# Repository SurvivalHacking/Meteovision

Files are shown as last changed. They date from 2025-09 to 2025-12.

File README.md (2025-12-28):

# Meteovision
A 3D weather station / Una stazione meteo 3D

## 📘 Descrizione / Description
Meteovision è una stazione meteo fuori dal comune.
Racchiusa in una campana di vetro, trasforma le previsioni del tempo in simboli luminosi: nuvole, fulmini, sole e luna si accendono con eleganza per mostrarti ciò che accadrà nel cielo.
Un anello di luce RGB, controllabile anche tramite APP, accentua l’atmosfera dell’ambiente, mentre un display grafico aggiunge movimento e dettaglio.
Con Meteovision, il meteo non si legge: si guarda, si vive.

Meteovision is an extraordinary weather station.
Enclosed in a glass dome, it transforms weather forecasts into luminous symbols: clouds, lightning, sun, and moon light up elegantly to show you what will happen in the sky.
An RGB light ring, which can also be controlled via an app, accentuates the atmosphere of the environment, while a graphic display adds movement and detail.
With Meteovision, you don't read the weather: you watch it, you experience it.

6b-IMG_0606_(00-00-04-06)

6a-IMG_0602_(00-00-08-22)

6-IMG_0601_(00-00-05-28)

4-IMG_0593_(00-01-49-21)

4-IMG_0593_(00-00-35-11)

4-IMG_0593_(00-00-02-10)

193-screen

---

## 🎛️ Schematic 

Screenshot 2025-09-08 alle 11 39 13

---
## 🎛️ Bill of material / Elenco materiali

* SSD1306 128x32 AMZ: https://amzn.to/3GfbspG
* SSD1306 128x32 ALI: https://s.click.aliexpress.com/e/_oovQgEA
* Anello/Ring 24LED (EXT:85mm/INT:70mm) AMZ: https://amzn.to/44hIzRx
* Vetro per/Glass for Redmi Watch 5 Active AMZ: https://amzn.to/3HZrPqO
* Vetro per/Glass for Redmi Watch 5 Active ALI: https://s.click.aliexpress.com/e/_oD0nSBC
* ESP32C3 AMZ: https://amzn.to/4kt5G2W
* ESP32C3 ALI: https://s.click.aliexpress.com/e/_DDST7Bj
* Pulsante/Pushbutton 6x6x7 DIP: https://s.click.aliexpress.com/e/_opuTCbP
* Resistenza/resistor 220R ALI: https://s.click.aliexpress.com/e/_okkfxGp
* Campana di vetro/Glass dome 9x12cm: https://s.click.aliexpress.com/e/_op1zvwS

Il link proposto è esattamente quella che ho utilizzato, siccome serve solo la parte in vetro è ragionevole pensare che altri tipi proposti da altri venditori siano utilizzabili.
Ho identificato altri 4 venditori che propongono la misura 9x12cm, ma non li ho provati effettivamente e non posso garantire che siano adatti, me se le misure sono rispettate dovrebbe andare benone. In generale se trovate una 'campana di vetro' o 'Glass dome' da 9x12cm dovrebbe andare bene. 
Link alternativi:

The link provided is exactly the one I used. Since only the glass part is needed, it is reasonable to assume that other types offered by other sellers are also suitable. I have identified four other sellers offering the 9x12cm size, but I have not actually tried them and cannot guarantee that they are suitable. However, if the measurements are correct, they should be fine. In general, if you find a 9x12cm ‘glass dome’ or ‘glass bell jar’, it should be fine. Alternative links:
* https://s.click.aliexpress.com/e/_oEAQ9RF
* https://s.click.aliexpress.com/e/_o2bXqxB
* https://s.click.aliexpress.com/e/_oCWLLnF
* Link affiliati / Affiliate links

---
## 👨‍💻 Programmazione modulo
Programmatore WEB (Solo per chrome): https://davidegatti.altervista.org/installaEsp32.php?progetto=MeteoVision

---
# 📝 Revisioni / Revisions
* V1.1 - 09/2025 - L'inserimento della città manualemnte via WEB non funzionava / Manually entering the city via the WEB did not work
* V1.2 - 09/2025 - Aggiunta la possibilità di vedere la previsione del giorno corrente / del giorno dopo e del giorno dopo ancora, mediante menù di configurazione WEB / Added the ability to view the forecast for the current day, the following day, and the day after that via the WEB configuration menu
* V1.3 - 10/2025 - Non erano gestite diverse tipologie di meteo tipo Neve da 600 a 699 e nebbia fumo e altre condizioni particolari da 700 a 799 / Different types of weather conditions such as snow from 600 to 699 and fog, smoke, and other special conditions from 700 to 799 were not managed.
* V1.4 - 10/2025 - Aggiunta scritta in mezzo alle due icone per evidenziare il giorno relativo alle previsioni / Text added between the two icons to highlight the day relating to the forecast. 
* V1.5 - 10/2025 - (By Marco Camerani) Aggiunta Modalità Notturna con orario impostabile da interfaccia web, Indicazione intensità e direzione vento, fix meteo led che non si aggiornano se in modalità diversa auto / Added Night Mode with time settings via web interface, wind speed and direction indicator, LED weather fixes that do not update if in a mode other than auto.
* V1.6 - 10/2025 - Bugfix salvataggio API key rivisto salvataggio di tutte le variabili più robusto gestione città con spazi e nomi lunghi a display
* V1.7 - 11/2025 - aggiunta la possibilita di previsioni 5 giorni e nuova interfaccia web by Marco Prunca
* V1.8 - 12/2025 - Sistemato problema sull'aggiornamento onghi 10 minuti su tutte le modalità
* V1.81 - 12/2025 - Aggiunto swithc per disabilitare l'effetto direzione e velocità del vento sull'anello.
* V1.9 - 12/2025 - Aggiunta animazione anello NeoPixel al cambio modalità e toggle di abilitazione nell'interfaccia web
* V1.91 - 12/2025 - Sistemato bug che facema smettere lèeffetto respiro dell'anello
* V1.92 - 12/2025 - Aggiunta la possibilità di configurare la connessione WIFI in modo manuale. Tutte le istruzioni per la configurazioni sono nel file wifi_config.h by Gigi Soft
* V1.93 - 12/2025 - Sistemato l'effetto respiro quando attivato l'indicatore del vento, e sistemazione per la connessione WIFI by Marco Prunca e Gigi Soft

* Nella cartella stampe 3D bambulab c'è un nuovo set di icone migliorate. / There is a new set of improved icons in the bambulab 3D prints folder.

---
## 🧾 Licenza / License

Questo progetto è distribuito con licenza
**Creative Commons – Attribuzione – Non Commerciale 4.0 Internazionale (CC BY-NC 4.0)**.

Puoi condividerlo e modificarlo liberamente, **citando l’autore**
(Davide Gatti / [survivalhacking](https://github.com/survivalhacking)) e **senza scopi commerciali**.

🔗 [https://creativecommons.org/licenses/by-nc/4.0/](https://creativecommons.org/licenses/by-nc/4.0/)

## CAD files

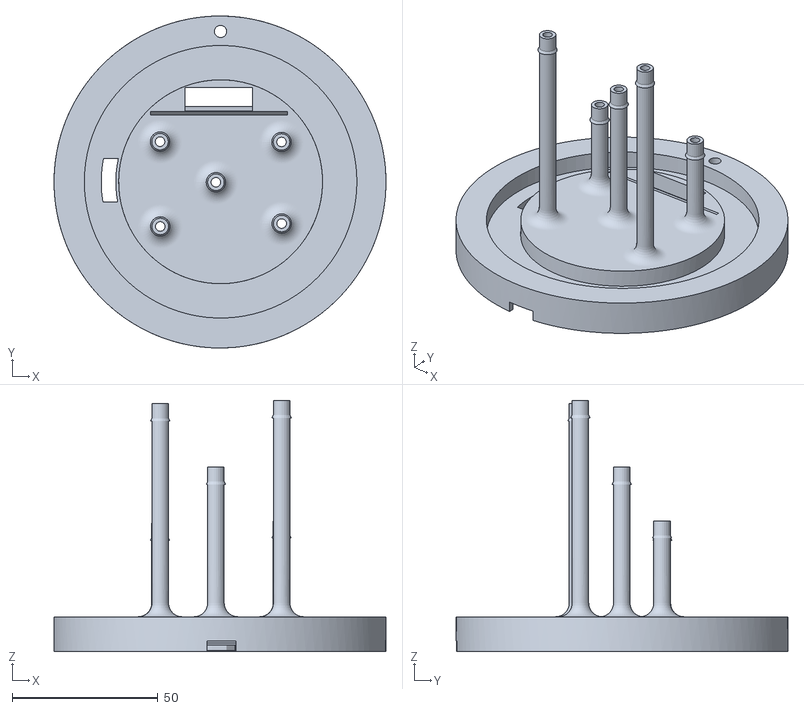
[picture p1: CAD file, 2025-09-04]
3d/Base (Argento glitter).stl
114.0 x 114.0 x 86.3

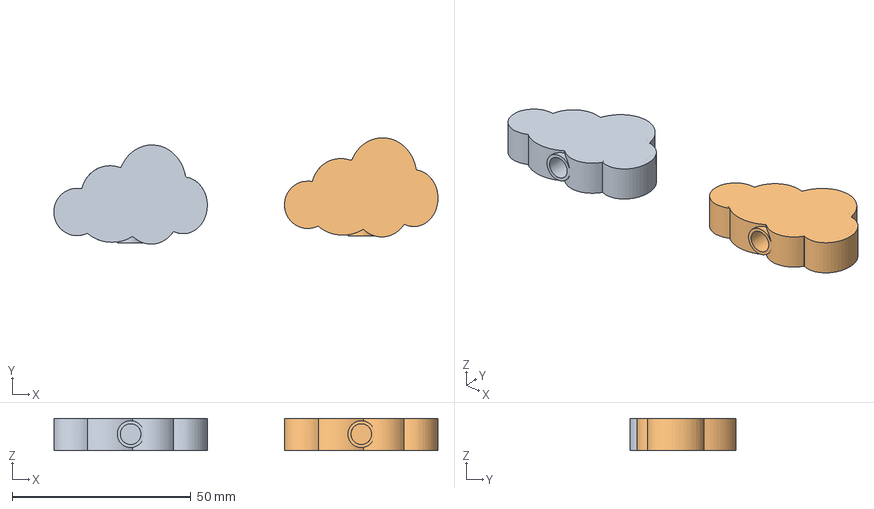
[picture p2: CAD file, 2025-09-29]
3d/Elementi COLOR/ANYCUBIC/Nuvola (AZZURRO-BIANCO) Anycubic.3mf
107.4 x 29.7 x 9.02 mm
Stunning Jaagub-Lappi (10).stl x 2

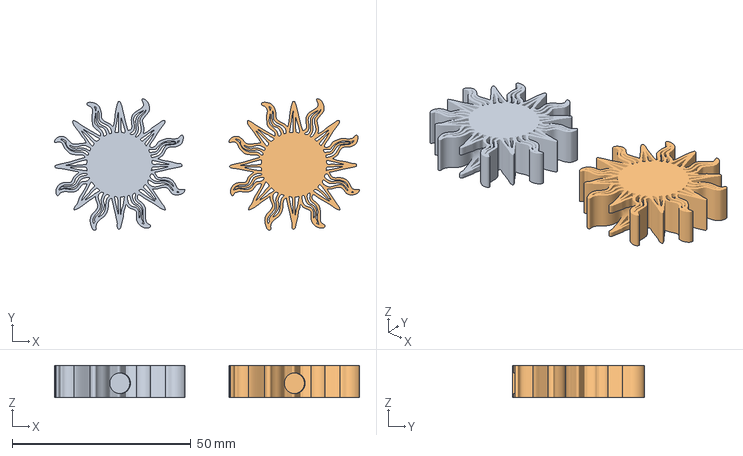
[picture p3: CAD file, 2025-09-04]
3d/Elementi COLOR/BAMBU/Sole (GIALLO-BIANCO Bambu.3mf
85.2 x 36.7 x 9.00 mm
SOLE.stl x 2

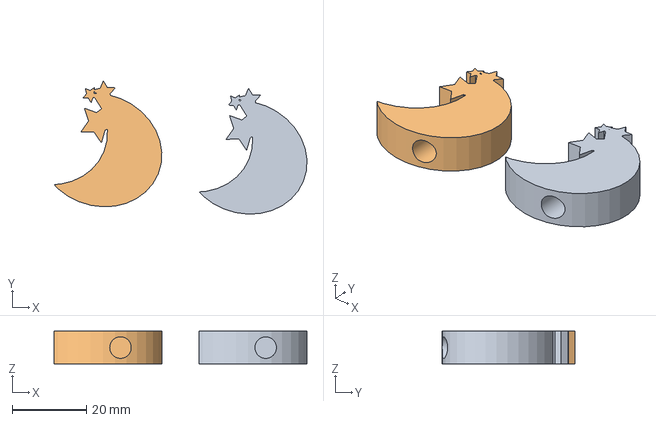
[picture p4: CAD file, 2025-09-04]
3d/Elementi COLOR/CREALITY/Luna (GRIGIO-BIANCO) Creality.3mf
68.2 x 35.9 x 8.86 mm
luna x 2

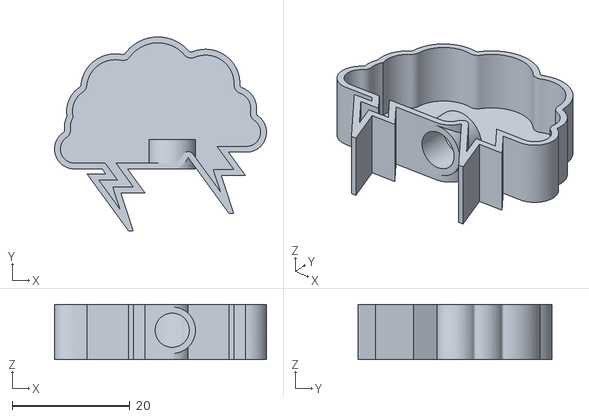
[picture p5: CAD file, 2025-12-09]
3d/Meteovision NEW ICON 5.8/FULMINI/Meteovision Foro 5.stl
36.0 x 32.9 x 9.40

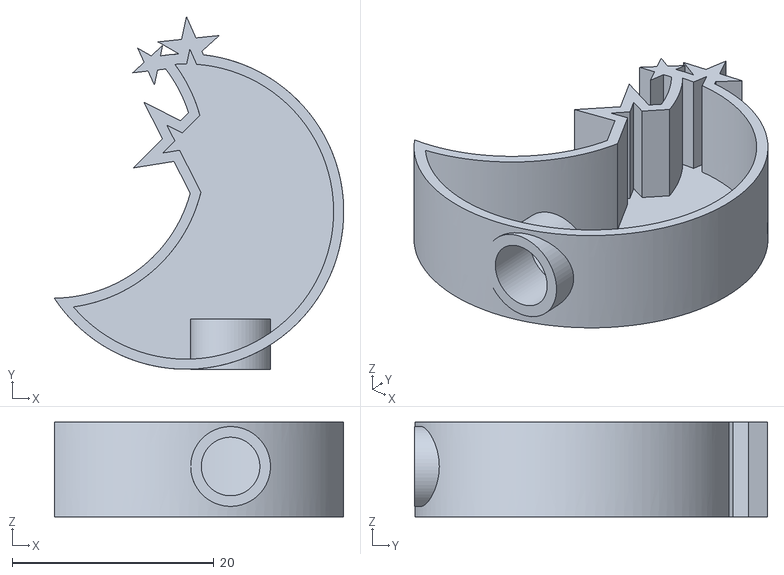
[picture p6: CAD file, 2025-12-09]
3d/Meteovision NEW ICON 5.8/LUNA/Luna_Base_Bianco.stl
28.7 x 35.0 x 9.40

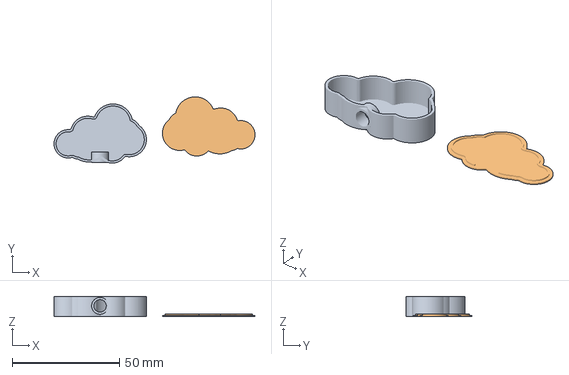
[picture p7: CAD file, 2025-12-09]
3d/Meteovision NEW ICON 5.8/NUVOLA/Nuvola_Cover_Bianco.3mf
93.8 x 30.9 x 9.40 mm
Nuvola2_Base_Azzurro.stl
Nuvola2_Cover_Azzurro.stl

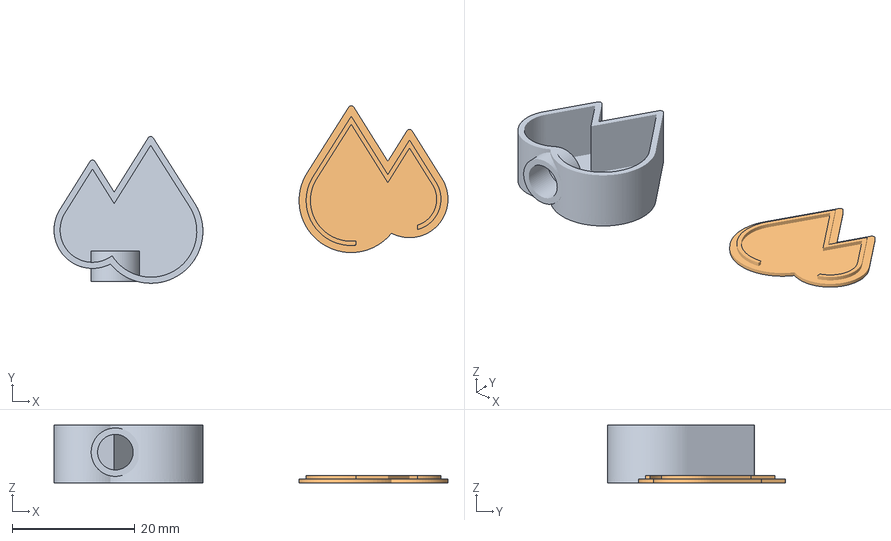
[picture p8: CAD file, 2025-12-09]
3d/Meteovision NEW ICON 5.8/PIOGGIA/Pioggia_Cover_Bianco.3mf
64.3 x 29.0 x 9.40 mm
Gocce_Base_Bianco.stl
Gocce_Cover_Bianco.stl

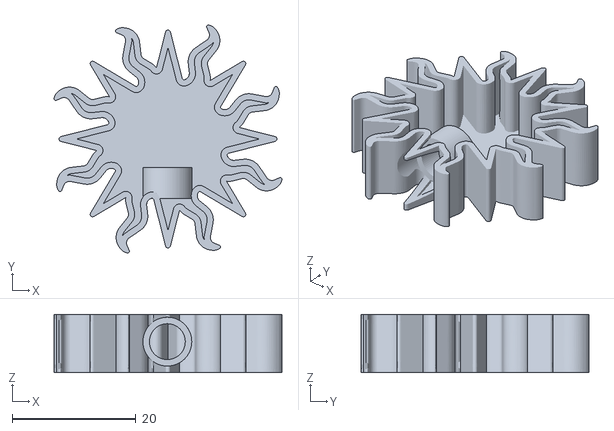
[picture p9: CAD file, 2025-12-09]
3d/Meteovision NEW ICON 5.8/SOLE/Sole_Base_Bianco.stl
36.9 x 36.9 x 9.40

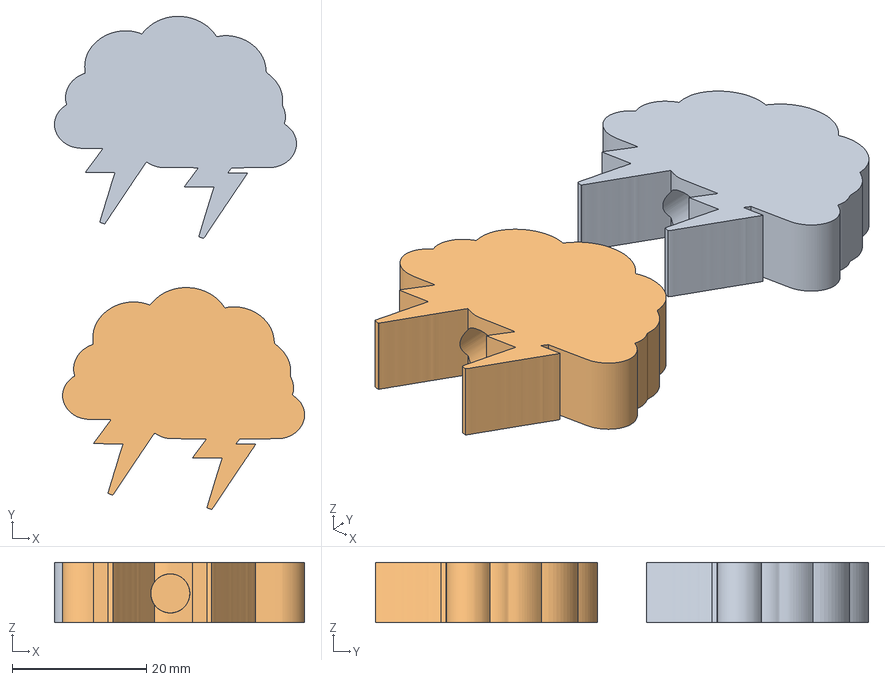
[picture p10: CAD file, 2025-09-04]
3d/Elementi COLOR/CREALITY/Fulmini (VIOLA-BIANCO) Creality.3mf
37.2 x 73.3 x 8.99 mm
Assemblaggio x 2

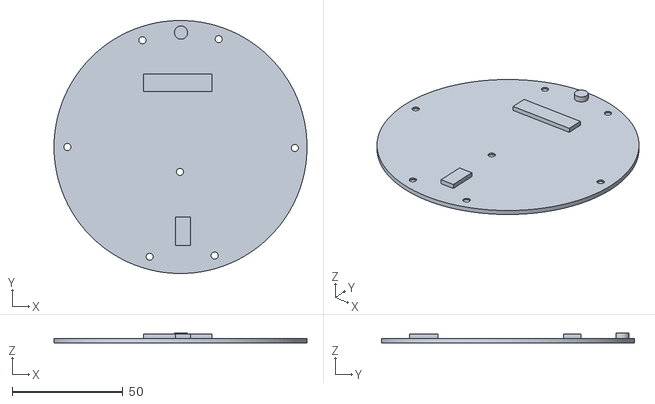
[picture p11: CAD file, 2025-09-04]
3d/Fondo (Argento glitter).stl
114.0 x 114.0 x 4.50

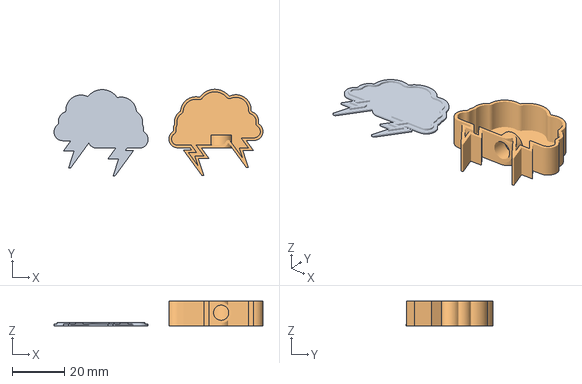
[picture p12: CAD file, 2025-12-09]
3d/Meteovision NEW ICON 5.8/FULMINI/Fulmine_Cover_Bianco.3mf
79.9 x 33.1 x 9.40 mm
Fulmine_Cover_Bianco.stl
Meteovision Foro 5.stl

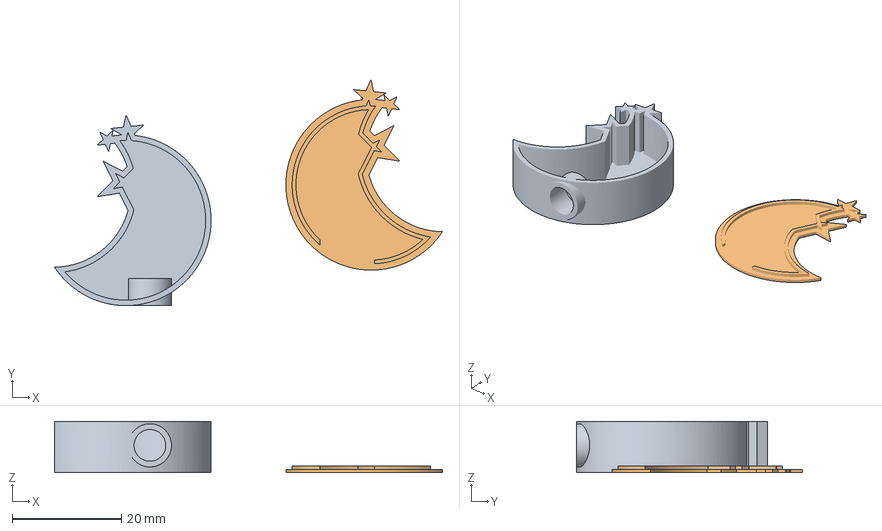
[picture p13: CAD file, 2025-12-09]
3d/Meteovision NEW ICON 5.8/LUNA/Luna_Cover_Bianco.3mf
71.0 x 41.5 x 9.40 mm
Luna_Base_Bianco.stl
Luna_Cover_Bianco.stl

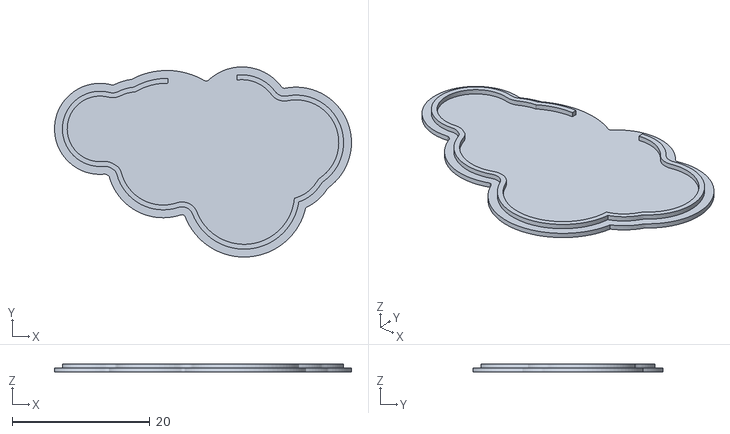
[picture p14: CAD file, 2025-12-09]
3d/Meteovision NEW ICON 5.8/NUVOLA/Nuvola2_Cover_Azzurro.stl
43.1 x 27.6 x 1.20

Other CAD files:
3d/Elementi COLOR/ANYCUBIC/Luna (GRIGIO-BIANCO) Anycubic.3mf
3d/Elementi COLOR/BAMBU/Nuvola (AZZURRO-BIANCO) Bambu.3mf
3d/Meteovision NEW ICON 5.8/PIOGGIA/Gocce_Cover_Bianco.stl
3d/Meteovision NEW ICON 5.8/SOLE/Sole_Cover_Bianco.3mf
3d/Anello (Traparente).stl
3d/Elementi (BIANCHI).stl
3d/Elementi COLOR/ANYCUBIC/Fulmini (VIOLA-BIANCO) Anycubic.3mf
3d/Elementi COLOR/ANYCUBIC/Gocce (BLU-BIANCO) Aycubic.3mf
3d/Elementi COLOR/ANYCUBIC/Sole (GIALLO-BIANCO Anycubic.3mf
3d/Elementi COLOR/BAMBU/Fulmini (VIOLA-BIANCO) Bambu.3mf
3d/Elementi COLOR/BAMBU/Gocce (BLU-BIANCO) Bambu.3mf
3d/Elementi COLOR/BAMBU/Luna (GRIGIO-BIANCO) Bambu.3mf
3d/Elementi COLOR/CREALITY/Gocce (BLU-BIANCO) Crality.3mf
3d/Elementi COLOR/CREALITY/Nuvola (AZZURRO-BIANCO) Creality.3mf
3d/Elementi COLOR/CREALITY/Sole (GIALLO-BIANCO Creality.3mf
3d/Meteovision NEW ICON 5.8/FULMINI/Fulmine_Cover_Bianco.stl
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

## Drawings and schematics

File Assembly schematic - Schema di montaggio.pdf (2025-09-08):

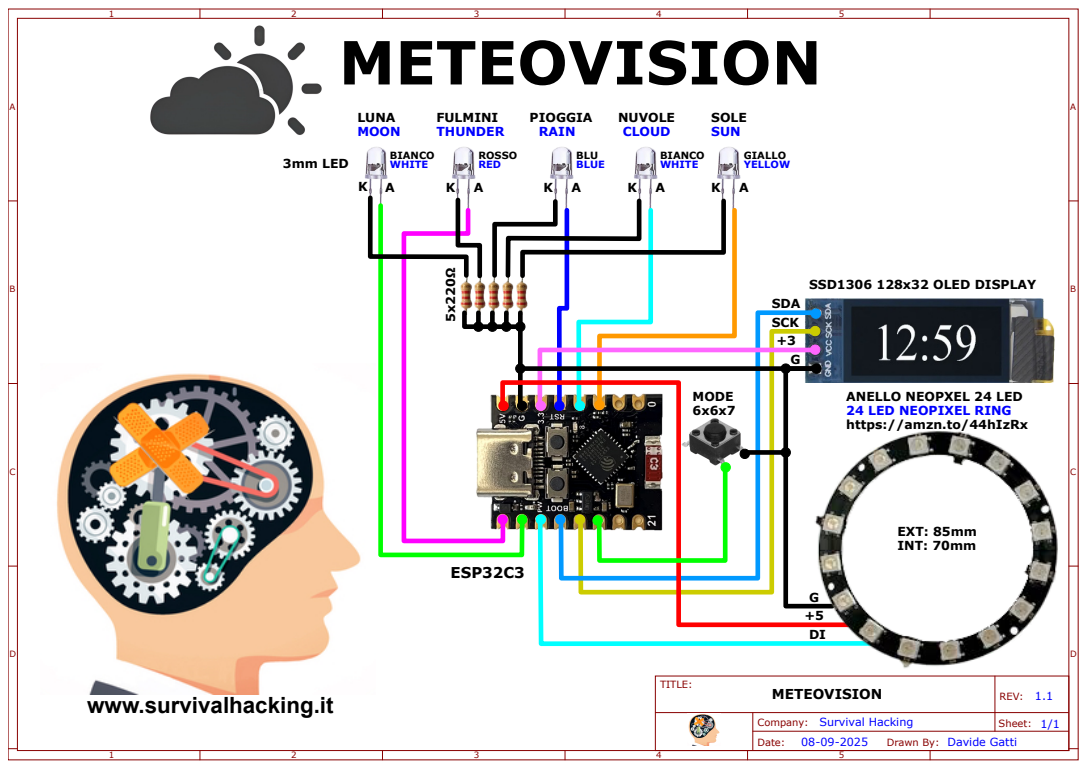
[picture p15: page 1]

SCK
+3

MODE
6x6x7

TITLE: | REV: 1.1

Company: Survival Hacking | Sheet: 1/1

Drawn By: Davide Gatti

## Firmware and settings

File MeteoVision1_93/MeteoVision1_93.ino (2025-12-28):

// V1.0 - 06/2025 - Meteovision by Davide Gatti - 2025 - www.survivalhacking.it
// V1.1 - 09/2025 - L'inserimento della città manualemnte via WEB non funzionava
// V1.2 - 09/2025 - Aggiunta la possibilità di vedere la previsione del giorno corrente / del giorno dopo e del giorno dopo ancora, mediante menù di configurazione WEB
// V1.3 - 10/2025 - Non erano gestite diverse tipologie di meteo tipo Neve da 600 a 699 e nebbia fumo e altre condizioni particolari da 700 a 799
// V1.4 - 10/2025 - Aggiunta scritta in mezzo alle due icone per evidenziare il giorno relativo alle previsioni
// V1.5 - 10/2025 - Aggiunta Modalità Notturna con orario impostabile da interfaccia web, Indicazione intensità e direzione vento, fix meteo led che non si aggiornano se in modalità diversa auto
// V1.6 - 10/2025 - Bugfix salvataggio API key rivisto salvataggio di tutte le variabili più robusto gestione città con spazi e nomi lunghi a display
// V1.7 - 11/2025 - aggiunta la possibilita di previsioni 5 giorni e interfaccia web by Marco Prunca
// V1.8 - 11/2025 - FIX: Aggiornamento meteo ogni 10 minuti funzionante per tutte le modalità
// V1.81- 12/2025 - Aggiunto swithc per disabilitare l'effetto direzione e velocità del vento sull'anello.
// V1.9 - 12/2025 - Aggiunta animazione anello NeoPixel al cambio modalità e toggle di abilitazione nell'interfaccia web
// V1.91- 12/2025 - Sistemato bug che facema smettere lèeffetto respiro dell'anello
// V1.92- 12/2025 - Aggiunta la possibilità di configurare la connessione WIFI in modo manuale. Tutte le istruzioni per la configurazioni sono nel file wifi_config.h by Gigi Soft
// V1.93- 12/2025 - Sistemato l'effetto respiro quando attivato l'indicatore del vento, e sistemazione per la connessione WIFI by Marco Prunca e Gigi Soft

#include <Arduino.h>
#include <Wire.h>
#include <Adafruit_GFX.h>       // Libreria grafica per display OLED
#include "Adafruit_SSD1306.h"   // Libreria per SSD1306 modificata per il supporto mirroring
#include <Adafruit_NeoPixel.h>  // Controllo anello LED WS2812

// Gestione connessione WiFi automatica
#include <WiFiManager.h>  // Permette setup Wi-Fi via interfaccia web

// Richieste HTTP per ottenere i dati meteo
#include <HTTPClient.h>
#include <ArduinoJson.h>  // Parsing JSON della risposta OpenWeather

#include "graphics.h"  // Contiene animazioni bitmap per display

// -- LIBRERIE PER GESTIONE TEMPO --
// Tempo standard C
#include <ctime>       // Include strutture come time_t, struct tm
#include <time.h>      // Funzioni di conversione ora/data
#include <sys/time.h>  // Per strutture temporali compatibili con ESP32

// Librerie NTP (Network Time Protocol)
#include <NTPClient.h>  // Permette sincronizzazione ora via Internet
#include <WiFiUdp.h>    // Necessario per comunicazione UDP usata da NTPClient

// Librerie custom per server web
#include <WebServer.h>    // Server HTTP in esecuzione su ESP32
#include <Preferences.h>  // Per salvare configurazioni persistenti

#include "secret.h"       // File con chiavi/API sensibili
#include "wifi_config.h"  // Configurazione WiFi manuale

// -- DEFINIZIONI HARDWARE DISPLAY OLED --
#define OLED_WIDTH 128
#define OLED_HEIGHT 32  // MODIFICATO: da 64 a 32 pixel
#define OLED_ADDR 0x3C  // Indirizzo I2C predefinito per display SSD1306
#define OLED_RESET -1   // Se il pin RESET non è collegato

// Istanzia il display OLED
Adafruit_SSD1306 display(OLED_WIDTH, OLED_HEIGHT, &Wire, OLED_RESET);

// -- DEFINIZIONI LED METEO INDIVIDUALI --
#define PIN_LED_SOLE 2       // LED per stato soleggiato
#define PIN_LED_NUVOLE 3     // LED per nuvole
#define PIN_LED_PIOGGIA 4    // LED per pioggia
#define PIN_LED_TEMPORALE 5  // LED per temporale
#define PIN_LED_LUNA 6       // LED per condizione notturna

// -- DEFINIZIONI PER ANELLO NEOPIXEL --
#define PIN_NEOPIXEL 7
#define NUM_NEOPIXELS 24  // Numero LED sull'anello
Adafruit_NeoPixel pixels(NUM_NEOPIXELS, PIN_NEOPIXEL, NEO_GRB + NEO_KHZ800);

// -- DEFINIZIONE PULSANTE FISICO --
#define PIN_PULSANTE 10  // Pulsante per cambiare modalità/luminosità

// -- DEFINIZIONI PER TEMPISMO DI SCHERMATA E METEO --
#define SCREEN_TEXT_DURATION 8000              // MODIFICATO: Ridotto per display più piccolo
#define SCREEN_ANIMATION_DURATION 5000         // MODIFICATO: Ridotto per display più piccolo
#define WEATHER_FETCH_INTERVAL 10 * 60 * 1000  // Ogni 10 minuti (in ms)

// Parametri effetto "respiro" LED (NeoPixel)
#define NEOPIXEL_BREATH_MIN 25       // Luminosità minima effetto respiro
#define NEOPIXEL_BREATH_MAX 255      // Luminosità massima
#define BREATH_UPDATE_SPEED 5        // Velocità animazione
#define NEOPIXEL_BOOT_ANIM_DELAY 50  // Delay tra accensioni LED iniziali

// Variabili per la gestione del pulsante
unsigned long buttonPressStartTime = 0;
bool buttonState = HIGH;
bool lastButtonState = HIGH;
unsigned long lastDebounceTime = 0;
const unsigned long debounceDelay = 50;
bool keypressed = false;

// Variabili per pressione lunga del pulsante
bool isLongPressMode = false;
const unsigned long LONG_PRESS_THRESHOLD = 1000;
const int BRIGHTNESS_CHANGE_INTERVAL = 100;
unsigned long lastBrightnessChangeTime = 0;

unsigned long lastScreenChange = 0;
bool showText = true;

// -- VARIABILI DI CONFIGURAZIONE PERSISTENTE --
Preferences preferences;

// Valori persistenti da conservare
char savedCity[40] = "Monza";
char savedCountryCode[5] = "IT";
int savedNeopixelBrightness = 200;
int savedMode = 0;
bool DisplayOneTime = false;
int Currentmode = 0;
int forecastDay = -1; // -1: Attuale (sempre all'accensione)
int forecastPeriod = 0; // 0: Mattino, 1: Pomeriggio, 2: Sera
#define MAX_MODE 11
bool nightModeEnabled = false;
int nightStartHour = 22;
int nightStartMinute = 00;
int nightEndHour = 7;
int nightEndMinute = 00;
bool windAnimationEnabled = true;
bool neopixelAnimationEnabled = true; // Nuova variabile per animazione cambio modalità

// Variabili per la visualizzazione del nome della modalità
bool showModeName = false;
unsigned long modeNameStartTime = 0;
const unsigned long MODE_NAME_DISPLAY_DURATION = 2000; // MODIFICATO: da 1 a 2 secondi

// Definizione delle modalità disponibili
#define MODO_AUTO 0
#define MODO_ROSSO 1
#define MODO_VERDE 2
#define MODO_BLU 3
#define MODO_VIOLA 4
#define MODO_CIANO 5
#define MODO_GIALLO 6
#define MODO_BIANCO 7
#define MODO_RING_OFF 8
#define MODO_LED_OFF 9
#define MODO_ALL_OFF 10
#define MODO_NOTTE 11

// -- VARIABILI GLOBALI NON SALVATE IN MEMORIA --
String ProductName = "MeteoVision V1.93";
String weatherDescription = "Ricerca...";
float windSpeed = 0;
int windDirection = 0;
int weatherConditionCode = 0;
float temperatureCelsius = 0.0;
int humidity = 0;
time_t sunriseTime = 0;
time_t sunsetTime = 0;
int animationFrame = 0;
const unsigned long WIND_SCAN_DURATION = 1000;
bool windScanning = false;
bool windAnimationActive = false;
int windScanFrame = 0;
unsigned long windAnimationStartTime = 0;
unsigned long animationStartTime = 0;
int windLedIndex = 0;

// Flag per forzare l'aggiornamento immediato del meteo
bool forceWeatherUpdate = false;

// Timer per l'aggiornamento periodico del meteo
unsigned long lastWeatherFetch = 0;

// -- GESTIONE RETE E SERVER WEB --
WiFiManager wm;
WebServer server(80);

// -- CLIENT NTP PER L'ORARIO DI SISTEMA --
WiFiUDP ntpUDP;
NTPClient timeClient(ntpUDP, "pool.ntp.org", 0, 60000);

// -- VARIABILI PER ANIMAZIONE DELL'ANELLO NEOPIXEL --
bool neopixelAnimationActive = true;
uint32_t neopixelBaseColor = pixels.Color(0, 0, 0);
bool neopixelBootAnimationInProgress = false;
bool neopixelModeChangeAnimation = false; // Nuova variabile per animazione cambio modalità
int neopixelAnimStep = 0;
unsigned long neopixelAnimLastUpdate = 0;
const int NEOPIXEL_ANIM_STEPS = NUM_NEOPIXELS + 5; // Numero di passi dell'animazione (LED + 5 extra per completamento)
const unsigned long NEOPIXEL_ANIM_DELAY = 40; // Delay tra i passi (più veloce per effetto fluido)

// Parametro personalizzato globale per WiFiManager
WiFiManagerParameter custom_api_key("api_key", "OpenWeatherMap API Key", "", 60);

// --- Connessione WiFi Manuale ---
bool connectWiFiManual() {
  Serial.println("\n==================================");
  Serial.println("TENTATIVO CONNESSIONE WIFI MANUALE");
  Serial.println("==================================");
  Serial.print("SSID: ");
  Serial.println(WIFI_SSID);
  Serial.print("Timeout: ");
  Serial.print(WIFI_CONNECT_TIMEOUT / 1000);
  Serial.println(" secondi");
  
  display.clearDisplay();
  display.setTextSize(1);
  display.setTextColor(SSD1306_WHITE);
  display.setCursor(0, 0);
  display.println("WiFi Manuale...");
  display.setCursor(0, 10);
  display.println("SSID:");
  display.setCursor(0, 18);
  display.println(WIFI_SSID);
  display.display();
  
  WiFi.disconnect(true);  
  delay(100);
  WiFi.mode(WIFI_STA);
  WiFi.begin(WIFI_SSID, WIFI_PASSWORD);
  
  unsigned long startAttempt = millis();
  int dotCount = 0;
  
  while (WiFi.status() != WL_CONNECTED && (millis() - startAttempt) < WIFI_CONNECT_TIMEOUT) {
    delay(500);
    Serial.print(".");
    
    dotCount = (dotCount + 1) % 4;
    display.clearDisplay();
    display.setTextSize(1);
    display.setCursor(0, 0);
    display.println("Connessione");
    display.setCursor(0, 10);
    for(int i = 0; i < dotCount; i++) {
      display.print(".");
    }
    display.setCursor(0, 20);
    display.print("Tempo: ");
    display.print((millis() - startAttempt) / 1000);
    display.print("s");
    display.display();
  }
  
  Serial.println();
  
  if (WiFi.status() == WL_CONNECTED) {
    Serial.println("✓ CONNESSIONE RIUSCITA!");
    Serial.print("Indirizzo IP: ");
    Serial.println(WiFi.localIP());
    Serial.print("Signal Strength (RSSI): ");
    Serial.print(WiFi.RSSI());
    Serial.println(" dBm");
    
    display.clearDisplay();
    display.setTextSize(1);
    display.setCursor(0, 0);
    display.println("WiFi CONNESSO!");
    display.setCursor(0, 10);
    display.print("IP: ");
    display.println(WiFi.localIP());
    display.setCursor(0, 20);
    display.print("RSSI: ");
    display.print(WiFi.RSSI());
    display.println("dBm");
    display.display();
    delay(3000);
    
    return true;
  } else {
    Serial.println("✗ CONNESSIONE FALLITA!");
    Serial.print("Stato WiFi: ");
    
    switch(WiFi.status()) {
      case WL_NO_SSID_AVAIL:
        Serial.println("SSID non trovato");
        display.clearDisplay();
        display.setTextSize(1);
        display.setCursor(0, 8);
        display.println("ERRORE WiFi:");
        display.setCursor(0, 16);
        display.println("SSID non trovato");
        break;
      case WL_CONNECT_FAILED:
        Serial.println("Password errata");
        display.clearDisplay();
        display.setTextSize(1);
        display.setCursor(0, 8);
        display.println("ERRORE WiFi:");
        display.setCursor(0, 16);
        display.println("Password errata");
        break;
      default:
        Serial.println("Errore sconosciuto");
        display.clearDisplay();
        display.setTextSize(1);
        display.setCursor(0, 8);
        display.println("ERRORE WiFi:");
        display.setCursor(0, 16);
        display.println("Timeout");
        break;
    }
    display.display();
    delay(3000);
    
    return false;
  }
}


// --- Mappatura traduzioni OpenWeatherMap (da codice numerico a descrizione ITA) ---
String getWeatherDescriptionItalian(int conditionCode) {
  if (conditionCode >= 200 && conditionCode < 300) return "Temporale";
  if (conditionCode >= 300 && conditionCode < 400) return "Pioggerella";
  if (conditionCode >= 500 && conditionCode < 600) {
    if (conditionCode == 500) return "Pioggia leggera";
    if (conditionCode == 501) return "Pioggia moderata";
    if (conditionCode == 502) return "Pioggia intensa";
    if (conditionCode == 503) return "Pioggia molto intensa";
    if (conditionCode == 504) return "Pioggia estrema";
    if (conditionCode == 511) return "Pioggia gelata";
    if (conditionCode == 520) return "Pioggerella intensa";
    if (conditionCode == 521) return "Acquazzone";
    if (conditionCode == 522) return "Forti acquazzoni";
    if (conditionCode == 531) return "Acquazzone irregolare";
    return "Pioggia";
  }
  if (conditionCode >= 600 && conditionCode < 700) return "Neve";
  if (conditionCode >= 700 && conditionCode < 800) {
    if (conditionCode == 701) return "Nebbia";
    if (conditionCode == 711) return "Fumo";
    if (conditionCode == 721) return "Foschia";
    if (conditionCode == 731) return "Vortici di sabbia/polvere";
    if (conditionCode == 741) return "Nebbia";
    if (conditionCode == 751) return "Sabbia";
    if (conditionCode == 761) return "Polvere";
    if (conditionCode == 762) return "Cenere vulcanica";
    if (conditionCode == 771) return "Colpo di vento";
    if (conditionCode == 781) return "Tornado";
    return "Atmosferico";
  }
  if (conditionCode == 800) return "Cielo sereno";
  if (conditionCode == 801) return "Poche nuvole";
  if (conditionCode == 802) return "Nuvole sparse";
  if (conditionCode == 803) return "Nuvole irregolari";
  if (conditionCode == 804) return "Cielo coperto";

  return "Sconosciuto";
}
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
void loop() {
  #if !USE_MANUAL_WIFI
    wm.process();
  #endif

  server.handleClient();
  handleButtonPress();

  unsigned long currentTime = millis();

  // --- GESTIONE CENTRALIZZATA DELL'AGGIORNAMENTO METEO ---
  // SPOSTATO QUI IN CIMA: viene eseguito SEMPRE, anche durante regolazione luminosità o cambio modalità
  // Controlla se è necessario un aggiornamento del meteo
  if (forceWeatherUpdate || (currentTime - lastWeatherFetch >= WEATHER_FETCH_INTERVAL)) {
    if (forceWeatherUpdate) {
      Serial.println("Aggiornamento forzato del meteo richiesto");
    } else {
      Serial.println("Aggiornamento periodico del meteo (10 minuti)");
    }

    fetchWeather();
    lastWeatherFetch = currentTime;
    forceWeatherUpdate = false;

    // Dopo l'aggiornamento, mostra le informazioni testuali
    lastScreenChange = currentTime;
    showText = true;
    DisplayOneTime = false;

    // Se siamo in modalità AUTO, aggiorna anche i LED
    if (Currentmode == MODO_AUTO) {
      updateWeatherLEDs();
      // Esegui l'animazione a onda fluida con il colore del meteo
      neopixelModeChangeAnimation = true;
      neopixelAnimStep = 0;
      neopixelAnimLastUpdate = millis();
    }
  }

  // Se siamo in modalità regolazione luminosità, non eseguire il resto del loop normale
  if (isLongPressMode) {
    return;
  }

  checkNightMode();

  // Gestione dell'animazione cambio modalità NeoPixel
  runNeopixelModeChangeAnimation();

  // Gestione della visualizzazione del nome della modalità
  if (showModeName) {
    if (millis() - modeNameStartTime >= MODE_NAME_DISPLAY_DURATION) {
      showModeName = false;
      // Torna alla visualizzazione normale del meteo
      showText = true;
      DisplayOneTime = false;
    } else {
      // Se stiamo mostrando il nome della modalità, non fare altro
      // Il display non viene aggiornato, quindi rimane il nome della modalità
      return;
    }
  }

  if (keypressed == false) {
    // GESTIONE MODALITÀ CON COMPORTAMENTI DIVERSI
    if (Currentmode == MODO_NOTTE) {
      // Modalità notte: solo display attivo, tutti i LED spenti
      if (showText) {
        if (currentTime - lastScreenChange >= SCREEN_TEXT_DURATION) {
          showText = false;
          lastScreenChange = currentTime;
          display.clearDisplay();
          currentFrame = 0;
        }
        if (!DisplayOneTime) {
          displayWeatherInfo();
          DisplayOneTime = true;
        }
      } else {
        if (currentTime - lastScreenChange >= SCREEN_ANIMATION_DURATION) {
          showText = true;
          lastScreenChange = currentTime;
          display.clearDisplay();
        }
        displayWeatherAnimation();
        DisplayOneTime = false;
      }
    }
    else if (Currentmode == MODO_ALL_OFF) {
      // Modalità tutto spento: display spento, tutti i LED spenti
      display.clearDisplay();
      display.display();
      AllLEDoff();
      pixels.clear();
      pixels.show();
    }
    else if (Currentmode == MODO_LED_OFF) {
      // Modalità LED spenti: solo display attivo, LED individuali spenti, anello spento
      if (showText) {
        if (currentTime - lastScreenChange >= SCREEN_TEXT_DURATION) {
          showText = false;
          lastScreenChange = currentTime;
          display.clearDisplay();
          currentFrame = 0;
        }
        if (!DisplayOneTime) {
          displayWeatherInfo();
          DisplayOneTime = true;
        }
      } else {
        if (currentTime - lastScreenChange >= SCREEN_ANIMATION_DURATION) {
          showText = true;
          lastScreenChange = currentTime;
          display.clearDisplay();
        }
        displayWeatherAnimation();
        DisplayOneTime = false;
      }
      
      // Assicura che i LED siano spenti
      AllLEDoff();
      pixels.clear();
      pixels.show();
    }
    else if (Currentmode == MODO_RING_OFF) {
      // Modalità anello spento: display attivo, LED individuali attivi, anello spento
      if (showText) {
        if (currentTime - lastScreenChange >= SCREEN_TEXT_DURATION) {
          showText = false;
          lastScreenChange = currentTime;
          display.clearDisplay();
          currentFrame = 0;
        }
      } else {
        if (currentTime - lastScreenChange >= SCREEN_ANIMATION_DURATION) {
          showText = true;
          lastScreenChange = currentTime;
          display.clearDisplay();
        }
      }

      if (showText) {
        if (!DisplayOneTime) {
          displayWeatherInfo();
          DisplayOneTime = true;
        }
      } else {
        displayWeatherAnimation();
        DisplayOneTime = false;
      }
      
      // Anello spento ma LED individuali attivi
      pixels.clear();
      pixels.show();
    }
    else {
      // Altre modalità (AUTO, COLORI, ecc.) - comportamento normale
      if (showText) {
        if (currentTime - lastScreenChange >= SCREEN_TEXT_DURATION) {
          showText = false;
          lastScreenChange = currentTime;
          display.clearDisplay();
          currentFrame = 0;
        }
      } else {
        if (currentTime - lastScreenChange >= SCREEN_ANIMATION_DURATION) {
          showText = true;
          lastScreenChange = currentTime;
          display.clearDisplay();
        }
      }

      // Gestione NeoPixel per modalità AUTO
      if (!neopixelBootAnimationInProgress && !neopixelModeChangeAnimation) {
        if (Currentmode == MODO_AUTO) {
          if (windAnimationEnabled && windScanning) {
            runWindDirectionScan(windLedIndex);
          } else if (windAnimationEnabled && windAnimationActive) {
            runWindAnimation();
          } else {
            runNeopixelAnimation();
          }
        }
      }

      if (showText) {
        if (!DisplayOneTime) {
          displayWeatherInfo();
          DisplayOneTime = true;
        }
      } else {
        displayWeatherAnimation();
        DisplayOneTime = false;
      }
    }
  }
}

// --- FUNZIONE PULSANTE CORRETTA ---
void handleButtonPress() {
  bool reading = digitalRead(PIN_PULSANTE);

  if (reading != lastButtonState) {
    lastDebounceTime = millis();
  }

  if ((millis() - lastDebounceTime) > debounceDelay) {
    if (reading != buttonState) {
      buttonState = reading;

      if (buttonState == LOW) {
        keypressed = true;
        buttonPressStartTime = millis();
        isLongPressMode = false;
        Serial.println("Pulsante premuto (inizia timer).");
      } else {
        unsigned long pressDuration = millis() - buttonPressStartTime;
        Serial.printf("Pulsante rilasciato. Durata: %lu ms.\n", pressDuration);

        if (!isLongPressMode && pressDuration < LONG_PRESS_THRESHOLD) {
          Serial.println("Pressione breve rilevata. Cambio modalita'.");
          Currentmode++;
          if (Currentmode > MAX_MODE) Currentmode = MODO_AUTO;
          showText = true;
          DisplayOneTime = false;

          // Mostra il nome della modalità per 2 secondi
          showModeName = true;
          modeNameStartTime = millis();

          SetRingColor(Currentmode, neopixelAnimationEnabled); // Con animazione se abilitata
          saveConfig();
          // Forza aggiornamento immediato quando si cambia modalità
          forceWeatherUpdate = true;
        }
        else if (isLongPressMode) {
          Serial.println("Uscita dalla regolazione luminosita'.");
          isLongPressMode = false;
          saveConfig();
          showText = true;
          DisplayOneTime = false;
        }
        
        keypressed = false;
      }
    }
  }

  lastButtonState = reading;

  if (buttonState == LOW && !isLongPressMode) {
    if (millis() - buttonPressStartTime >= LONG_PRESS_THRESHOLD) {
      isLongPressMode = true;
      Serial.println("Entrato in modalita' regolazione luminosita'.");
      lastBrightnessChangeTime = millis();
      drawBrightnessBar(savedNeopixelBrightness);
    }
  }

  if (isLongPressMode && buttonState == LOW) {
    if (millis() - lastBrightnessChangeTime >= BRIGHTNESS_CHANGE_INTERVAL) {
      lastBrightnessChangeTime = millis();

      savedNeopixelBrightness += 5;
      if (savedNeopixelBrightness > 255) {
        savedNeopixelBrightness = 10;
      }
      
      pixels.setBrightness(savedNeopixelBrightness);
      pixels.show();
      
      drawBrightnessBar(savedNeopixelBrightness);
    }
  }
}
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

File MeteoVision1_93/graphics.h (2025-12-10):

// --- BITMAPS PER LE ANIMAZIONI DISPLAY ---
// Icone ridimensionate a 24x24 pixel per display 128x32 con scritta giorno

// Animazione SOLE (3 frame per effetto pulsante) - 24x24 pixel
const unsigned char PROGMEM sun_anim_1[] = {
	0x00, 0x18, 0x00, 0x00, 0x38, 0x00, 0x00, 0x10, 0x00, 0x00, 0x00, 0x00,
	0x00, 0x00, 0x30, 0x70, 0x00, 0x30, 0x00, 0x7e, 0x00, 0x01, 0xff, 0x80,
	0x03, 0xff, 0xc0, 0x07, 0xff, 0xe0, 0x07, 0xff, 0xe0, 0x0f, 0xff, 0xf0,
	0x0f, 0xff, 0xf6, 0x0f, 0xff, 0xfe, 0x0f, 0xff, 0xf0, 0x07, 0xff, 0xe0,
	0x07, 0xff, 0xe0, 0x03, 0xff, 0xc0, 0x01, 0xff, 0x80, 0x00, 0x7e, 0x00,
	0x38, 0x00, 0x38, 0x18, 0x00, 0x00, 0x00, 0x00, 0x00, 0x00, 0x18, 0x00
};
const unsigned char PROGMEM sun_anim_2[] = {
	0x00, 0x00, 0x00, 0x00, 0x10, 0x00, 0x01, 0x30, 0x00, 0x01, 0x80, 0x00,
	0x00, 0x00, 0x00, 0x00, 0x00, 0x00, 0x00, 0x1e, 0x18, 0x00, 0xff, 0x1c,
	0x01, 0xff, 0x80, 0x03, 0xff, 0xc0, 0xe3, 0xff, 0xc0, 0x07, 0xff, 0xe0,
	0x07, 0xff, 0xe0, 0x07, 0xff, 0xe4, 0x03, 0xff, 0xc6, 0x03, 0xff, 0xc7,
	0x01, 0xff, 0x80, 0x00, 0xff, 0x80, 0x38, 0x7f, 0x00, 0x38, 0x1e, 0x00,
	0x00, 0x00, 0x00, 0x00, 0x00, 0x00, 0x00, 0x01, 0x80, 0x00, 0x0c, 0x80
};
const unsigned char PROGMEM sun_anim_3[] = {
	0x00, 0x00, 0x00, 0x00, 0x30, 0x00, 0x00, 0x30, 0x30, 0x00, 0x00, 0x00,
	0x00, 0x00, 0x00, 0x00, 0x00, 0x00, 0x00, 0x7e, 0x00, 0x18, 0xff, 0x00,
	0x1c, 0xff, 0x80, 0x07, 0xff, 0xe0, 0x07, 0xff, 0xe0, 0x07, 0xff, 0xe0,
	0x07, 0xff, 0xe0, 0x07, 0xff, 0xe0, 0x07, 0xff, 0xe0, 0x07, 0xff, 0xe0,
	0x07, 0xff, 0xe0, 0x38, 0xff, 0x80, 0x00, 0xff, 0x1c, 0x00, 0x7e, 0x00,
	0x00, 0x00, 0x00, 0x00, 0x00, 0x00, 0x00, 0x18, 0x00, 0x00, 0x18, 0x00
};
const unsigned char* sun_animation[] = {sun_anim_1, sun_anim_2, sun_anim_3};
const int SUN_ANIM_FRAMES = 3;
const int SUN_ANIM_WIDTH = 24;
const int SUN_ANIM_HEIGHT = 24;

// Animazione NUVOLE - 24x24 pixel
const unsigned char PROGMEM cloud_anim_1[] = {
	0x00, 0x00, 0x00, 0x00, 0x00, 0x00, 0x00, 0x00, 0x00, 0x00, 0x3c, 0x00,
	0x00, 0xff, 0x00, 0x01, 0xff, 0x80, 0x03, 0xff, 0xc0, 0x07, 0xff, 0xe0,
	0x7f, 0xff, 0xe0, 0xff, 0xff, 0xf0, 0xff, 0xff, 0xfc, 0xff, 0xff, 0xfe,
	0xff, 0xff, 0xff, 0x7f, 0xff, 0xff, 0xff, 0xff, 0xff, 0xff, 0xff, 0xff,
	0xff, 0xff, 0xfe, 0xff, 0xff, 0xfc, 0xff, 0x7f, 0xf8, 0xff, 0x00, 0x00,
	0xfe, 0x00, 0x00, 0x00, 0x00, 0x00, 0x00, 0x00, 0x00, 0x00, 0x00, 0x00
};

const unsigned char PROGMEM cloud_anim_2[] = {
	0x00, 0x00, 0x00, 0x00, 0x00, 0x00, 0x00, 0x00, 0x00, 0x00, 0x3c, 0x00,
	0x00, 0xff, 0x00, 0x01, 0xff, 0x80, 0x03, 0xff, 0xc0, 0x07, 0xff, 0xe0,
	0x7f, 0xff, 0xe0, 0xff, 0xff, 0xf0, 0xff, 0xff, 0xfc, 0xff, 0xff, 0xfe,
	0xff, 0xff, 0xff, 0xff, 0xe7, 0xff, 0xff, 0x81, 0xff, 0xff, 0x9f, 0xff,
	0x7e, 0x3f, 0xff, 0x0e, 0x7f, 0xfe, 0x06, 0xff, 0x78, 0x00, 0xff, 0x00,
	0x00, 0x7e, 0x00, 0x00, 0x00, 0x00, 0x00, 0x00, 0x00, 0x00, 0x00, 0x00
};

const unsigned char PROGMEM cloud_anim_3[] = {
	0x00, 0x00, 0x00, 0x00, 0x00, 0x00, 0x00, 0x00, 0x00, 0x00, 0x3c, 0x00,
	0x00, 0xff, 0x00, 0x01, 0xff, 0x80, 0x03, 0xff, 0xc0, 0x07, 0xff, 0xe0,
	0x7f, 0xff, 0xe0, 0xff, 0xff, 0xf0, 0xff, 0xff, 0xfc, 0xff, 0xff, 0xfe,
	0xff, 0xff, 0xff, 0xff, 0xff, 0xef, 0xff, 0xff, 0x00, 0xff, 0xfe, 0x7f,
	0x7f, 0xf9, 0xff, 0x0f, 0xf7, 0xff, 0x07, 0xef, 0xff, 0x00, 0x03, 0xff,
	0x00, 0x00, 0xff, 0x00, 0x00, 0x00, 0x00, 0x00, 0x00, 0x00, 0x00, 0x00
};

const unsigned char* cloud_animation[] = {cloud_anim_1, cloud_anim_2, cloud_anim_3};
const int CLOUD_ANIM_FRAMES = 3;
const int CLOUD_ANIM_WIDTH = 24;
const int CLOUD_ANIM_HEIGHT = 24;

// Animazione PIOGGIA - 24x24 pixel
const unsigned char PROGMEM rain_anim_1[] = {
	0x00, 0x00, 0x00, 0x00, 0x00, 0x00, 0x00, 0x3e, 0x00, 0x00, 0xff, 0x80,
	0x03, 0xff, 0xc0, 0x03, 0xff, 0xc0, 0x1f, 0xff, 0xc0, 0x7f, 0xff, 0xe0,
	0xff, 0xff, 0xf8, 0xff, 0xff, 0xfc, 0xff, 0xe1, 0xfe, 0xff, 0xc0, 0xff,
	0xff, 0x40, 0x7f, 0xff, 0x40, 0x3f, 0xfe, 0xc0, 0x1f, 0x7e, 0xe0, 0x1f,
	0x3e, 0xe1, 0x0f, 0x0e, 0xe0, 0x0e, 0x00, 0xe0, 0x00, 0x00, 0xe0, 0x00,
	0x00, 0x00, 0x00, 0x00, 0x00, 0x00, 0x00, 0x00, 0x00, 0x00, 0x00, 0x00
};

const unsigned char PROGMEM rain_anim_2[] = {
	0x00, 0x00, 0x00, 0x00, 0x00, 0x00, 0x00, 0x3e, 0x00, 0x00, 0xff, 0x80,
	0x03, 0xff, 0xc0, 0x03, 0xff, 0xc0, 0x1f, 0xff, 0xc0, 0x7f, 0xff, 0xe0,
	0xff, 0xff, 0xf8, 0xff, 0xff, 0xfc, 0xff, 0xff, 0xfe, 0xff, 0xe1, 0xff,
	0xff, 0xf0, 0xff, 0xff, 0xf0, 0x7f, 0xff, 0xf0, 0x3f, 0x7f, 0x00, 0x1f,
	0x3e, 0x01, 0x0f, 0x1e, 0x01, 0x0e, 0x06, 0xe1, 0x0e, 0x00, 0xe0, 0x0e,
	0x00, 0xe0, 0x0e, 0x00, 0x00, 0x00, 0x00, 0x00, 0x00, 0x00, 0x00, 0x00
};

const unsigned char PROGMEM rain_anim_3[] = {
	0x00, 0x00, 0x00, 0x00, 0x00, 0x00, 0x00, 0x3e, 0x00, 0x00, 0xff, 0x80,
	0x03, 0xff, 0xc0, 0x03, 0xff, 0xc0, 0x1f, 0xff, 0xc0, 0x7f, 0xff, 0xe0,
	0xff, 0xff, 0xf8, 0xff, 0xff, 0xfc, 0xff, 0xff, 0xfe, 0xff, 0xff, 0xff,
	0xff, 0xff, 0xff, 0xff, 0xff, 0xff, 0xff, 0xff, 0xff, 0x7f, 0xff, 0x1f,
	0x3f, 0xfe, 0x0f, 0x1f, 0xfc, 0x07, 0x03, 0xf8, 0x06, 0x00, 0x00, 0x0e,
	0x00, 0x00, 0x0e, 0x00, 0x00, 0x00, 0x00, 0x00, 0x00, 0x00, 0x00, 0x00
};

const unsigned char* rain_animation[] = {rain_anim_1, rain_anim_2, rain_anim_3};
const int RAIN_ANIM_FRAMES = 3;
const int RAIN_ANIM_WIDTH = 24;
const int RAIN_ANIM_HEIGHT = 24;

// Animazione TEMPORALE - 24x24 pixel
const unsigned char PROGMEM storm_anim_1[] = {
	0x00, 0x00, 0x00, 0x00, 0x00, 0x00, 0x00, 0x7e, 0x00, 0x00, 0xff, 0x80,
	0x03, 0xff, 0xc0, 0x03, 0xff, 0xc0, 0x1f, 0xff, 0xc0, 0x7f, 0xff, 0xe0,
	0xff, 0xff, 0xf8, 0xff, 0xfc, 0x1c, 0xff, 0xf8, 0x0e, 0xff, 0xf8, 0x0e,
	0xff, 0xfe, 0x1e, 0xff, 0xee, 0x0e, 0xff, 0xfe, 0x00, 0x7f, 0xee, 0x00,
	0x3f, 0xfe, 0x00, 0x1f, 0xdf, 0xf8, 0x07, 0xff, 0xf0, 0x00, 0x0f, 0xf0,
	0x00, 0x07, 0xe0, 0x00, 0x03, 0xc0, 0x00, 0x03, 0x80, 0x00, 0x00, 0x00
};

const unsigned char PROGMEM storm_anim_2[] = {
	0x00, 0x00, 0x00, 0x00, 0x00, 0x00, 0x00, 0x7e, 0x00, 0x00, 0xff, 0x80,
	0x03, 0xff, 0xc0, 0x03, 0xff, 0xc0, 0x1f, 0xff, 0xc0, 0x7f, 0xff, 0xe0,
	0xff, 0xfc, 0xf8, 0xff, 0xf8, 0x1c, 0xff, 0xf0, 0x0e, 0xff, 0xf0, 0x0e,
	0xff, 0xe0, 0x0e, 0xff, 0xe0, 0x0c, 0xff, 0xc1, 0xc0, 0x7f, 0xc3, 0xc0,
	0x3f, 0x87, 0xf8, 0x1f, 0x87, 0xf8, 0x07, 0x8f, 0xf0, 0x00, 0x0f, 0xc0,
	0x00, 0x01, 0xe0, 0x00, 0x00, 0xe0, 0x00, 0x00, 0xc0, 0x00, 0x00, 0x00
};

const unsigned char PROGMEM storm_anim_3[] = {
	0x00, 0x00, 0x00, 0x00, 0x00, 0x00, 0x00, 0x7e, 0x00, 0x00, 0xff, 0x80,
	0x03, 0xff, 0xc0, 0x03, 0xff, 0xc0, 0x1f, 0xff, 0xc0, 0x7f, 0xff, 0xe0,
	0xff, 0xff, 0xf8, 0xff, 0xfc, 0x1c, 0xff, 0xf8, 0x0e, 0xff, 0xf0, 0x0e,
	0xff, 0xf0, 0x4e, 0xff, 0xe0, 0xce, 0xff, 0xc1, 0xc0, 0x7f, 0xc1, 0xe0,
	0x3f, 0x83, 0xe0, 0x1f, 0x87, 0xfe, 0x07, 0x87, 0xfe, 0x00, 0x01, 0xf8,
	0x00, 0x00, 0x70, 0x00, 0x00, 0x70, 0x00, 0x00, 0x60, 0x00, 0x00, 0x00
};

const unsigned char* storm_animation[] = {storm_anim_1, storm_anim_2, storm_anim_3};
const int STORM_ANIM_FRAMES = 3;
const int STORM_ANIM_WIDTH = 24;
const int STORM_ANIM_HEIGHT = 24;
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

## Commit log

2025-09-04 3D printer files / File per stampa 3D
    [Anello (Traparente).stl, Base (Argento glitter).stl, Elementi (BIANCHI).stl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]
2025-09-04 Arduino IDE Code / Codice per arduino IDE
2025-09-04 Assembly schematic / Schema di assemblaggio
2025-09-08 Assembly schematic - Schema di montaggio
2025-09-21 Arduino IDE Code / Codice per arduino IDE V1.1
2025-10-04 Arduino IDE Code 1.4/ Codice 1.4 per arduino IDE
2025-10-04 Versione aggiornata - Updated version
    [Meteovision icon.3mf]
2025-10-23 Arduino IDE Code 1.5/ Codice 1.5 per arduino IDE
2025-11-11 Enhance README with description and schematic
    Added a description section, schematic, and updated the bill of materials with links. Removed redundant entries and improved formatting.
2025-11-23 Arduino IDE Code 1.7/ Codice 1.7 per arduino IDE
2025-12-07 Arduino Ide Sketch
2025-12-09 Nuove Icone by Marco Prunca
    [Fulmine_Cover_Bianco.3mf, Fulmine_Cover_Bianco.stl, Gocce_Base_Bianco.stl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]
